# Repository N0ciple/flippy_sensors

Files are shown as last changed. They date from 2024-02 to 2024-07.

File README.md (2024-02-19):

# Flippy Sensors 🐬

flippy sensor is a WIP multi-sensor board for the flipper zero. It includes a SHT30 for temperature and humidity, a LSM6DS3TR-C for gyro and accelerometer and a PA1010D for GPS. A first batch is currently in production at JLCPCB.

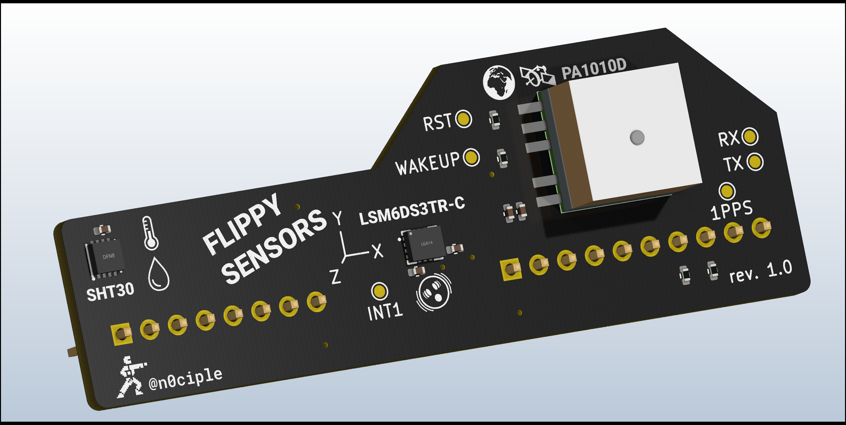
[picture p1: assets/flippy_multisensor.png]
Front

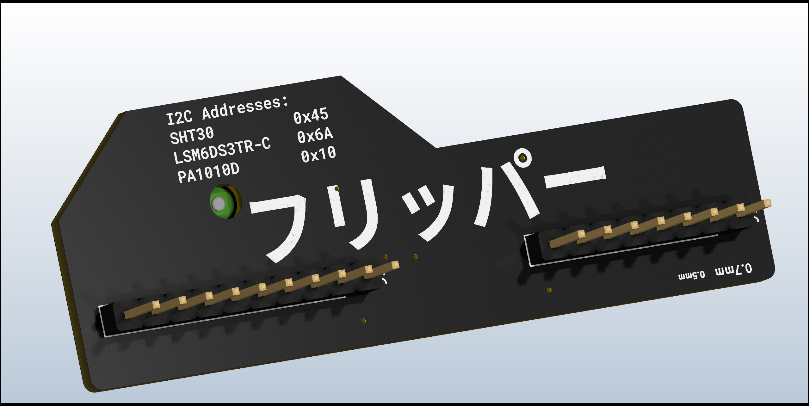
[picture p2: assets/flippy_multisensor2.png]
Back


## sensors list
- **PA1010D**: GPS/GNSS [datasheet](https://cdn-learn.adafruit.com/assets/assets/000/084/295/original/CD_PA1010D_Datasheet_v.03.pdf?1573833002)
- **LSM6DS3TR-C**: Accelerometer and gyroscope [datasheet](https://www.mouser.fr/datasheet/2/389/lsm6ds3tr_c-1761429.pdf)
- **SHT30**: Temperature and humidity [datasheet](https://www.mouser.com/datasheet/2/682/Sensirion_Humidity_Sensors_SHT3x_Datasheet_digital-971521.pdf)

All sensors communicate with I2C
| sensor | I2C address |
| --- | --- |
| PA1010D | `0x10` |
| LSM6DS3TR-C | `0x6A` |
| SHT30 | `0x44` |

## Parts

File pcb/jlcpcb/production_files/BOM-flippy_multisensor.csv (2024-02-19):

Comment | Designator | Footprint | LCSC
100n | C1,C2,C3,C5 | C_0402_1005Metric | C1525
10k | R1,R2,R3,R4 | R_0402_1005Metric | C25744
SHT30-DIS-B10KS | U1 | DFN-8_L2.5-W2.5-P0.50-BL-EP | C2687423
1u | C4 | C_0402_1005Metric | C52923
LSM6DS3TR-C | U2 | LGA-14_L3.0-W2.5-P0.50-TL | C967633

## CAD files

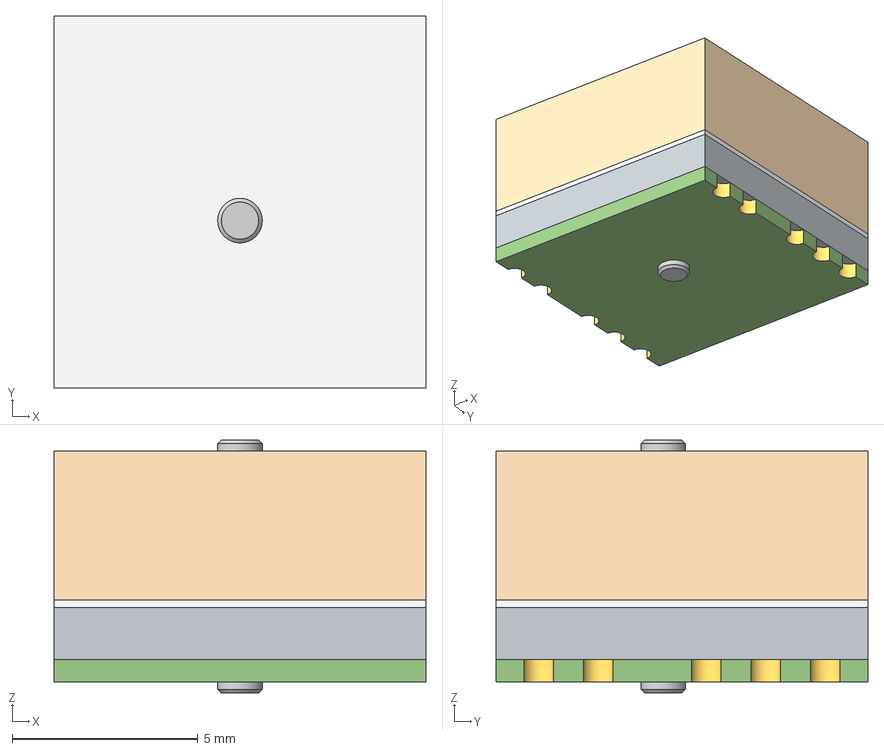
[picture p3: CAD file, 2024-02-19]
pcb/PA1010D_libs/PA1010D_3D.step
10.0 x 10.0 x 6.80 mm

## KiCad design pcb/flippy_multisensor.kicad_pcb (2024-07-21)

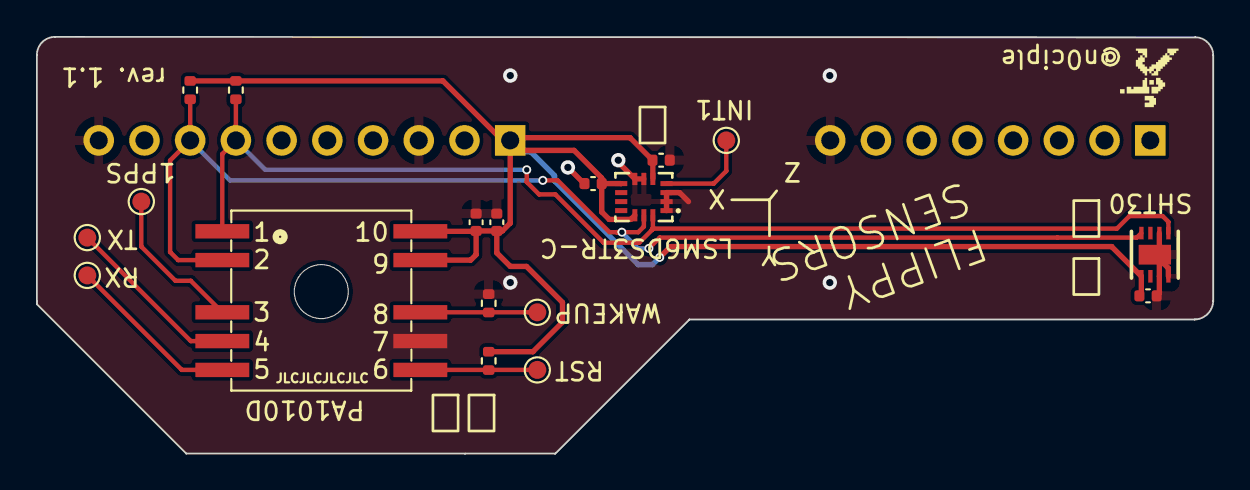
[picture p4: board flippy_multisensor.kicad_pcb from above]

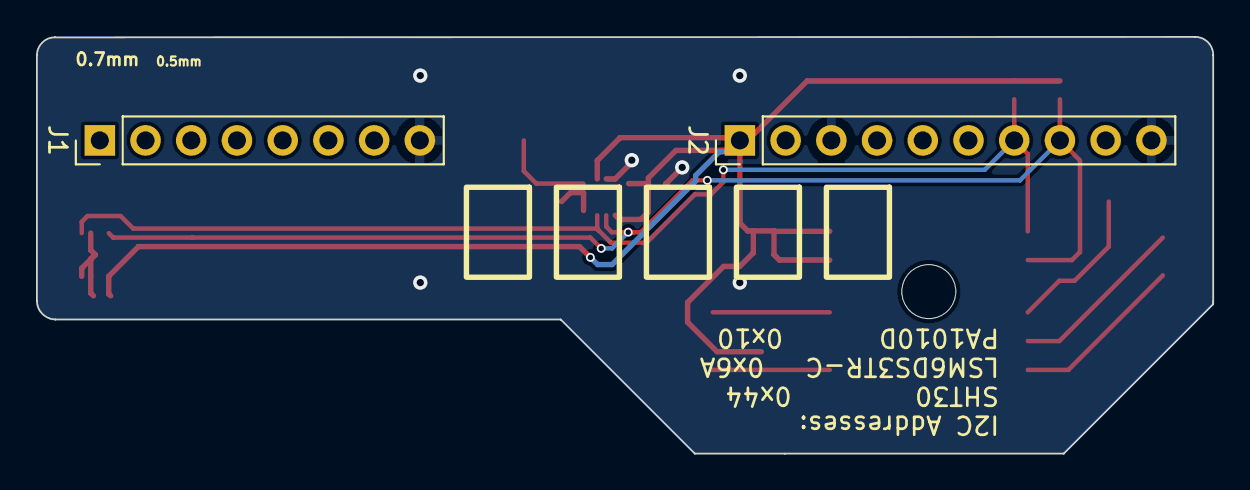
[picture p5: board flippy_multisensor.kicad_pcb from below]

Board: 2 copper layers, 65.4 x 23.2 mm, 20 parts (2 on the bottom side), 10 nets.

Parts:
1PPS: 1PPS; TestPoint_Pad_D1.0mm
C1, C2, C3, C5: 100n; C_0402_1005Metric
C4: 1u; C_0402_1005Metric
INT1: TestPoint; TestPoint_Pad_D1.0mm
J1: PINHD_1x8_Male; PinHeader_1x08_P2.54mm_Vertical
J2: PINHD_1x10_Male; PinHeader_1x10_P2.54mm_Vertical
R1, R2, R3, R4: 10k; R_0402_1005Metric
RST: reset pin; TestPoint_Pad_D1.0mm
RX: UART RX; TestPoint_Pad_D1.0mm
TX: UART TX; TestPoint_Pad_D1.0mm
U1: SHT30-DIS-B10KS; DFN-8_L2.5-W2.5-P0.50-BL-EP
U2: LSM6DS3TR-C; LGA-14_L3.0-W2.5-P0.50-TL
U3: PA1010D; PA1010D_footprint
WAKEUP: wakup pin; TestPoint_Pad_D1.0mm

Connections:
+3.3V: C1.1, C2.1, C3.1, C4.1, C5.1, J2.1, R1.2, R2.1, R4.1, U1.5 (VDD), U2.5 (VDDIO), U2.8 (VDD), U2.12 (CS), U3.9 (VBACKUP), U3.10 (VCC)
GND: C1.2, C2.2, C3.2, C4.2, C5.2, J1.8, J2.3, J2.10, R3.2, U1.2 (ADDR), U1.7 (R), U1.8 (VSS), U1.9 (EP), U2.1 (SDO/SA0), U2.2 (SDx), U2.3 (SCx), U2.6 (GND), U2.7 (GND), U3.7 (GND)
unnamed: INT1.1, U2.4 (INT1)
unnamed: 1PPS.1, U3.3 (1PPS)
unnamed: RX.1, U3.5 (RX)
unnamed: TX.1, U3.4 (TX)
unnamed: R3.1, U3.8 (WAKEUP), WAKEUP.1
unnamed: R4.2, RST.1, U3.6 (~RESET)
SCL: J2.8, R2.2, U1.4 (SCL), U2.13 (SCL), U3.2 (SCL)
SDA: J2.7, R1.1, U1.1 (SDA), U2.14 (SDA), U3.1 (SDA)

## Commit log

2024-02-19 add kicad files
    [BOM-flippy_multisensor.csv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]
2024-02-19 Add PA1010D 3D model
    [PA1010D_3D.3mf]
2024-02-19 Convert 3D model to STEP
    [PA1010D_3D.3mf, PA1010D_3D.step]
2024-02-19 remove schematic backup
2024-02-19 update PCB
    [flippy_multisensor.kicad_pcb, flippy_multisensor.kicad_sch]
2024-02-19 update PA1010D 3D model
    [PA1010D_3D.step]
2024-02-19 update test points labels
    [flippy_multisensor.kicad_pcb]
2024-02-26 correct the SHT30 i2c address on the label
    [flippy_multisensor.kicad_pcb]
